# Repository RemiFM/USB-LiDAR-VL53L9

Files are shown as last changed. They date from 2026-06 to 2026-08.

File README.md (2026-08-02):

# USB-C LiDAR Node (VL53L9)



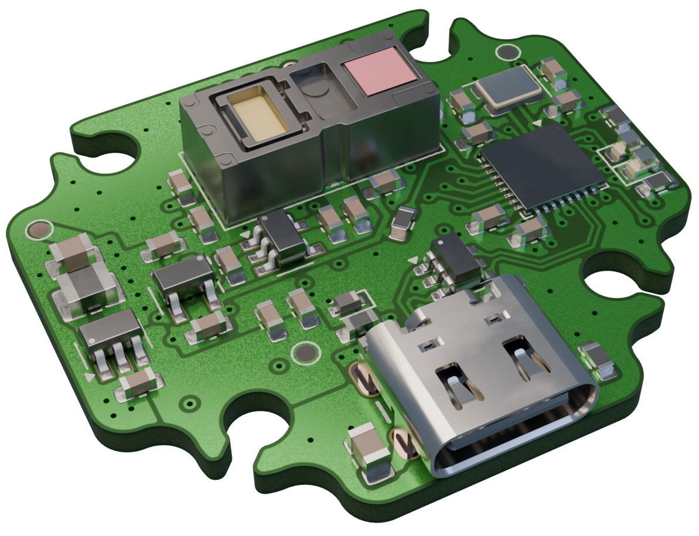
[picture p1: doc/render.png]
PCB render


A compact and low-cost USB device with integrated LiDAR sensor and IMU. This hardware node packages STMicroelectronics' VL53L9 advanced direct Time-of-Flight (dToF) matrix LiDAR with a 6-axis IMU into a plug-and-play USB-C device. Designed for mobile robotics, micro-UAVs, and academic SLAM research. The hardware is designed in KiCad 10.

## System Architecture
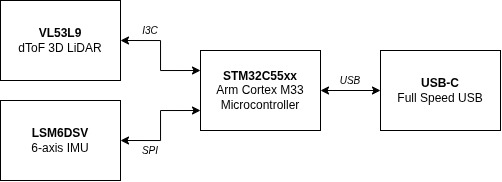
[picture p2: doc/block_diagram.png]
Block diagram showing VL53L9 LiDAR and LSM6DSV IMU connected via I3C to an STM32C55xx MCU, which interfaces to the host over USB Full-Speed


| Feature | Detail | Datasheet |
|---|---|---|
| **LiDAR** | ST VL53L9CX dToF module with up to 54×42 (2.3 k) discrete ranging zones, 5 cm–8.8 m range | [link](https://www.st.com/resource/en/datasheet/vl53l9cx.pdf)
| **IMU** | ST LSM6DSV 6-axis IMU with embedded sensor fusion engine, orientation quaternions generated on-chip | [link](https://www.st.com/resource/en/datasheet/lsm6dsv.pdf)

## Data Format
Raw binary packet framing is used instead of verbose text formats (JSON/CSV) to stay well within the 12 Mbps USB Full-Speed ceiling while imposing zero processing overhead on the MCU.

Per the VL53L9CX datasheet (DS14879, Table 2), the I3C interface is specified for a 12.5 MHz bus clock and a 12.5 Mbps output data rate. Full resolution is hard-limited to 30 Hz. Two pre-configured profiles are available:

| Profile | Output Matrix | Frame Rate |
|---|---|---|
| **Full Resolution** *(default)* | 54 × 42 zones | 30 Hz |
| **Binned Navigation** *(high-velocity)* | 24 × 20 zones | 60 Hz |

## Mechanical Specs

The PCB measures 34 × 30 mm and has 4× M3 mounting holes on a 20 mm square pitch, fitting small drone frame stacks.

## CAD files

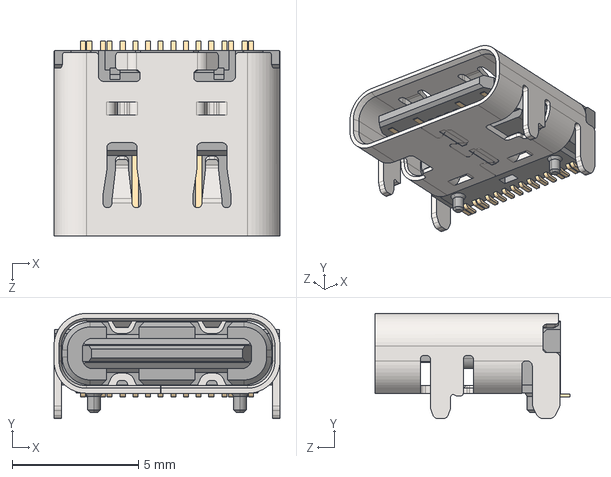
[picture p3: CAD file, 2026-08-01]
pcb/3d/USB4106-GF-A.stp
8.94 x 4.16 x 7.73 mm
HSG

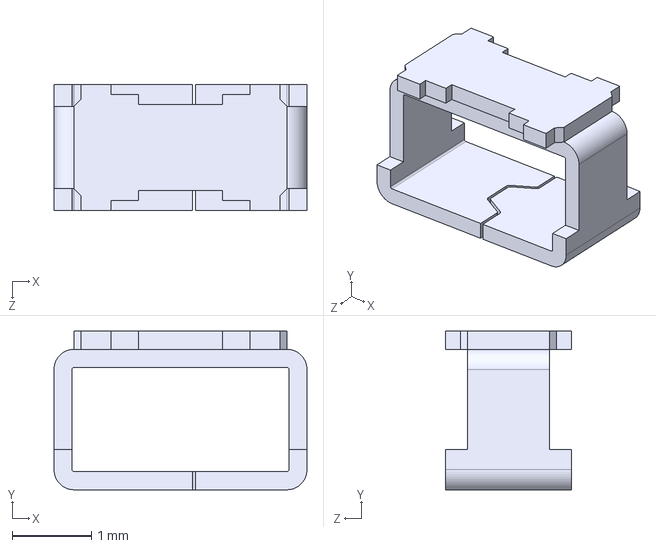
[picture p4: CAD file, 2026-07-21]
pcb/3d/RCWCTE.stp
3.20 x 2.01 x 1.60 mm

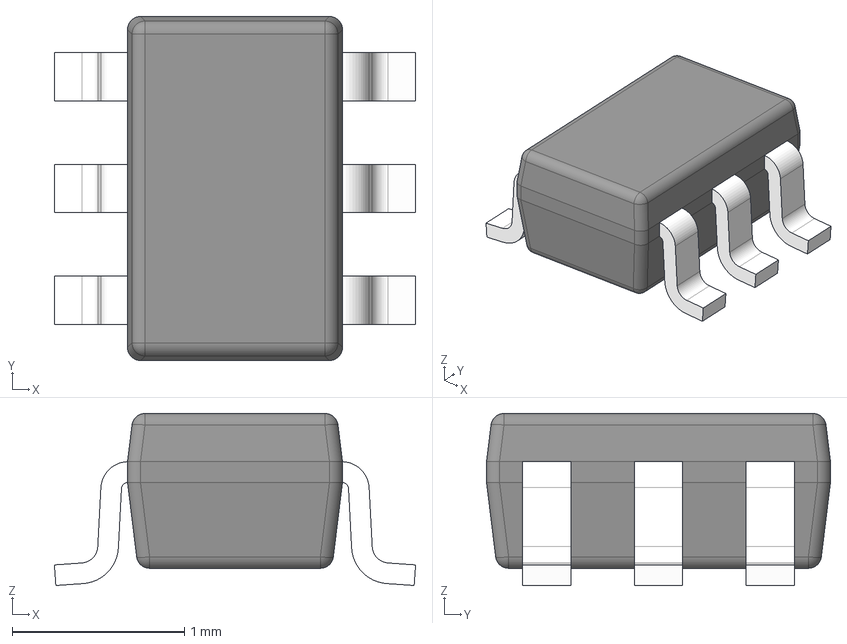
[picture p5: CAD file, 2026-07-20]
pcb/3d/DCK0006A.stp
2.10 x 2.00 x 1.00 mm
BODY-SOT
LEAD-SOT x 6
PIN1-ID

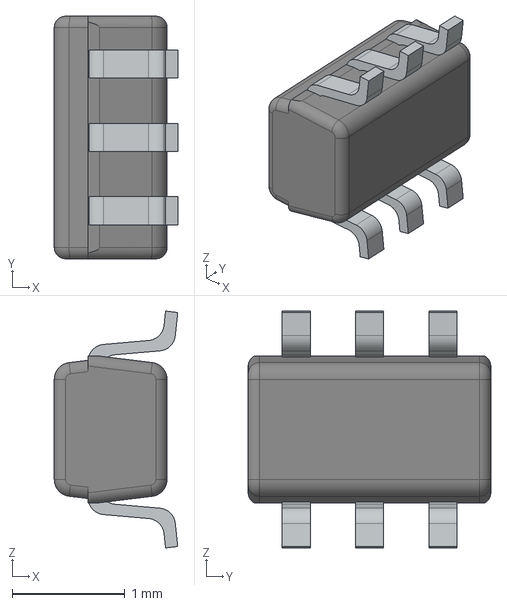
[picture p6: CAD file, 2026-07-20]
pcb/3d/Diodes-In-SOT363.stp
1.09 x 2.15 x 2.10 mm
LF01

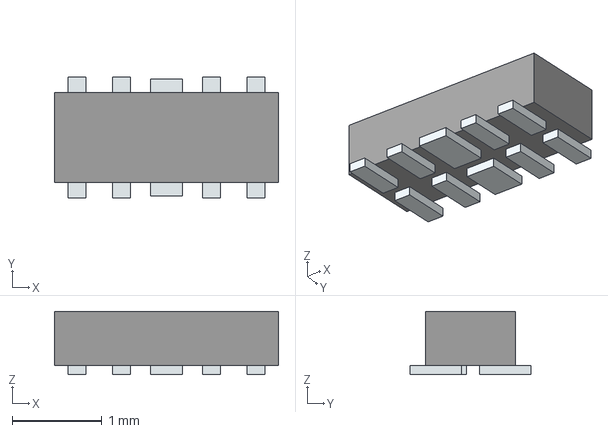
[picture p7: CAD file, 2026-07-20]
pcb/3d/D3V3X4U10LP-7.stp
2.50 x 1.35 x 0.705 mm
Pins

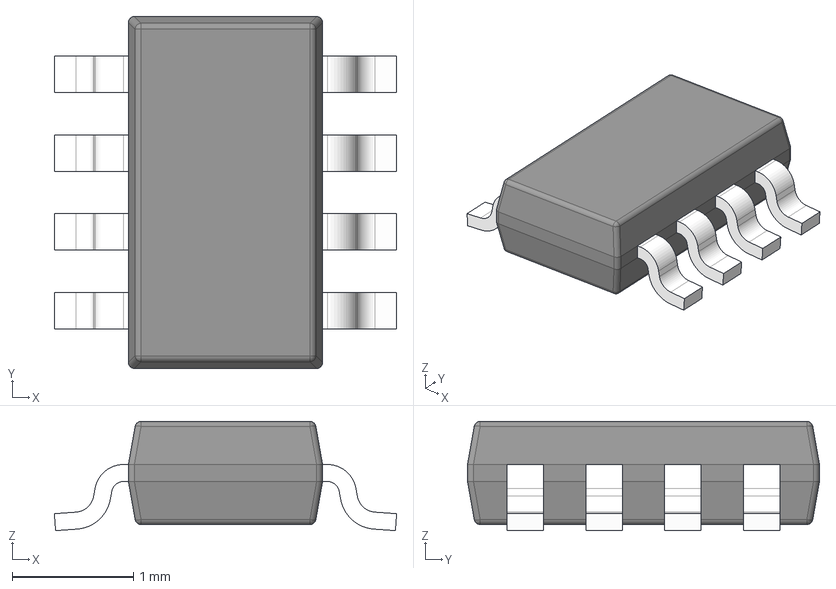
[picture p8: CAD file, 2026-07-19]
pcb/3d/DDF0008A.stp
2.82 x 2.90 x 0.9 mm
BODY-SO
LEAD-SO x 8
PIN1-ID

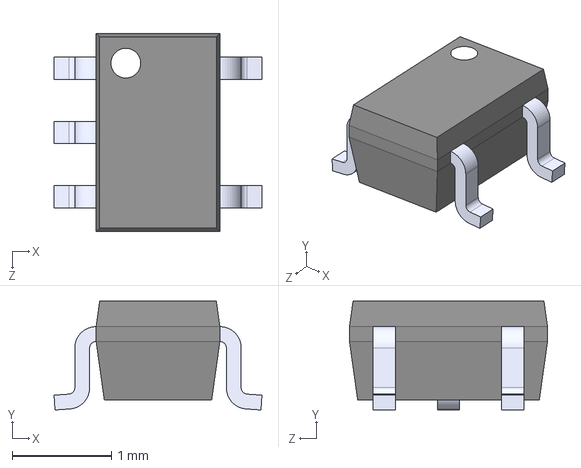
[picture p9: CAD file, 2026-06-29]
pcb/3d/SN74LVC1G17DCKR.stp
2.10 x 1.10 x 2.00 mm

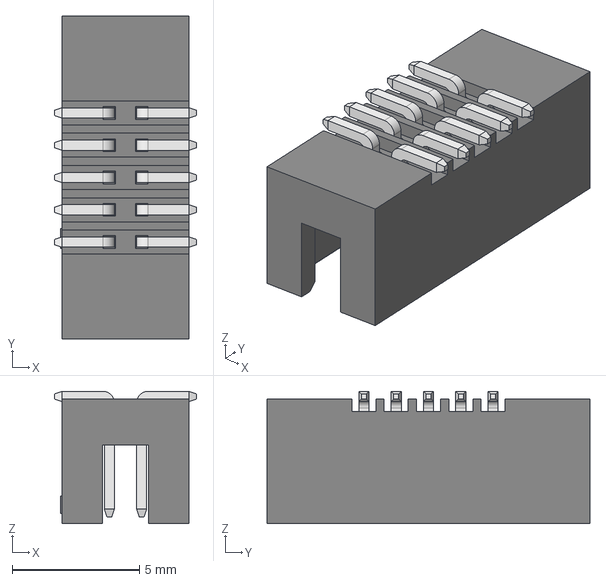
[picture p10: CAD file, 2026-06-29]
pcb/3d/3221-10-0300-00 3D.stp
5.60 x 12.7 x 5.20 mm
801-2195-10-K
2195SM-PIN x 10

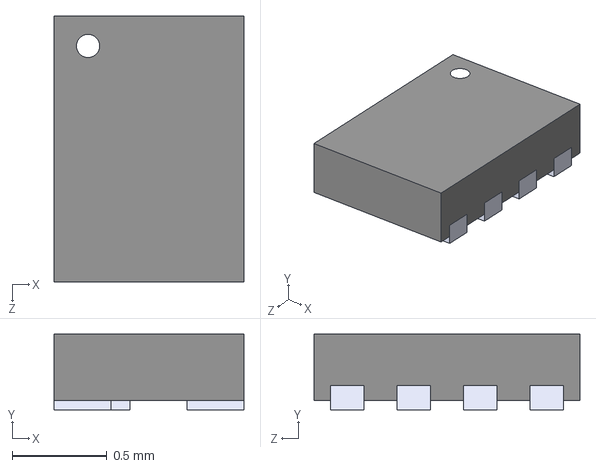
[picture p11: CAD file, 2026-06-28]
pcb/3d/LSF0102DQER.stp
1.00 x 0.4 x 1.40 mm

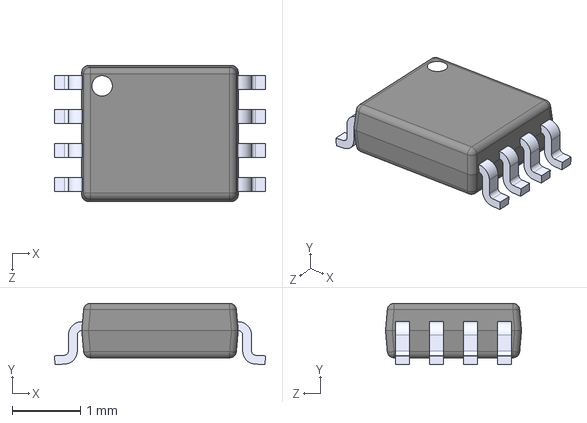
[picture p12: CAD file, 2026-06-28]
pcb/3d/LSF0102DCUR.stp
3.10 x 0.9 x 2.00 mm

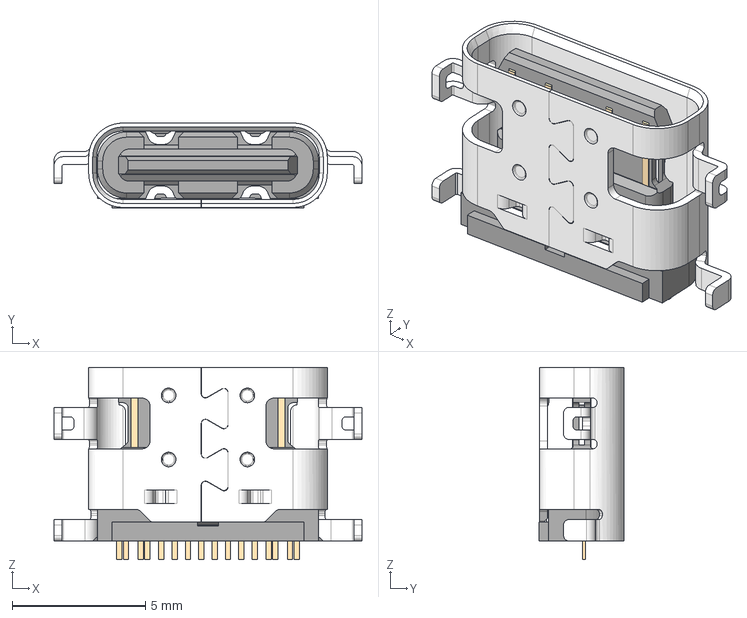
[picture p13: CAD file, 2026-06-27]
pcb/3d/USB4510-03-1-A.stp
11.5 x 3.18 x 7.20 mm

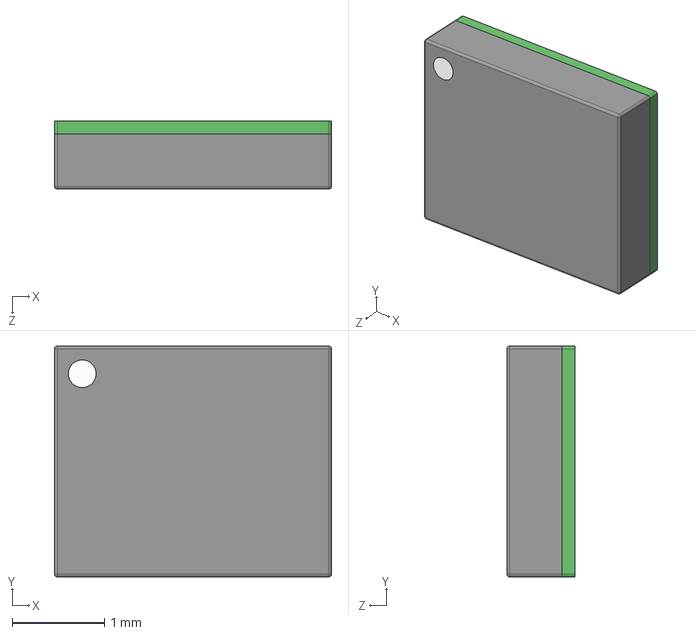
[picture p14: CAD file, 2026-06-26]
pcb/3d/LSM6DSV16BXTR.stp
3.00 x 2.50 x 0.74 mm

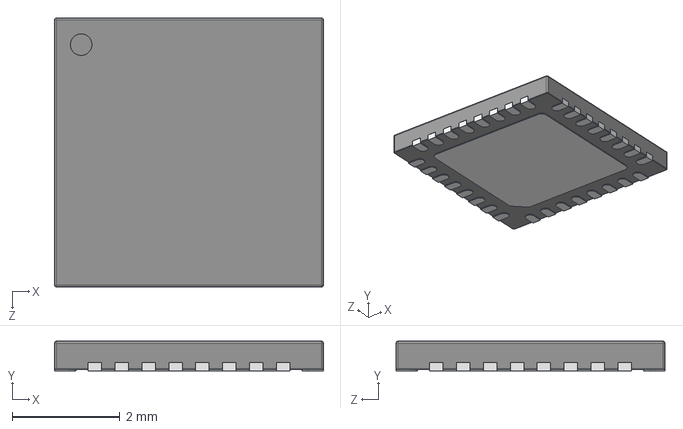
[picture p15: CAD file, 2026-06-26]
pcb/3d/STM32C551KEU6.stp
5.00 x 0.55 x 5.00 mm

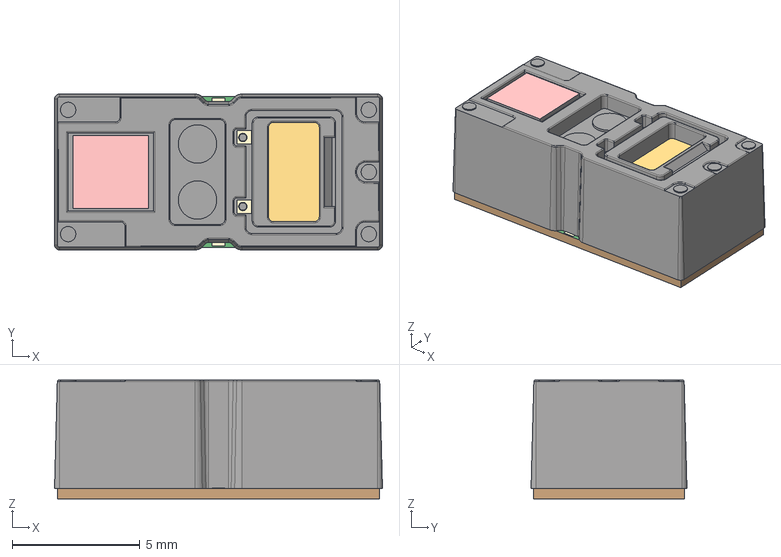
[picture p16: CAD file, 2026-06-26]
pcb/3d/VL53L9CX.stp
12.8 x 6.10 x 4.64 mm

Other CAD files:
pcb/3d/TLV73328PDBVR.stp

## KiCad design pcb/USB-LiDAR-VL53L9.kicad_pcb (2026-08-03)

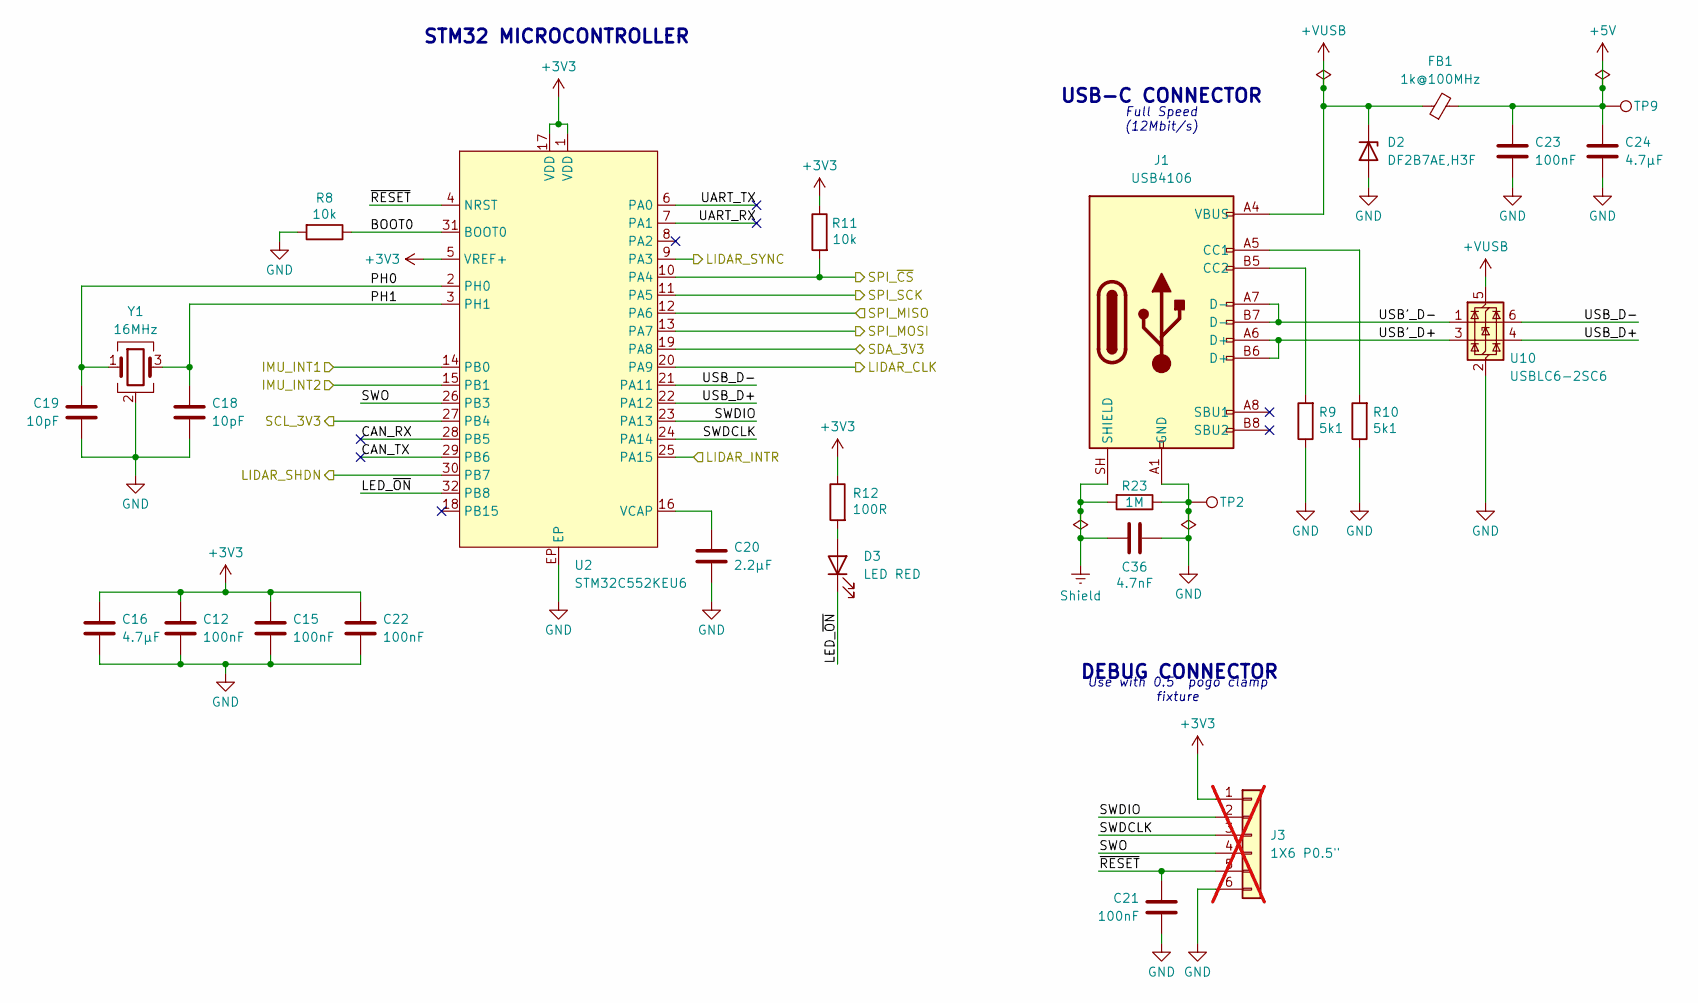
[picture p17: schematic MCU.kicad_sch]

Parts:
C12, C15, C21, C22, C23: 100nF; C_0603_1608Metric; Digi-Key 311-1088-1-ND
C16, C24: 4.7µF; C_0603_1608Metric; Digi-Key 311-1785-1-ND
C18, C19: 10pF; C_0603_1608Metric; Digi-Key 311-1058-1-ND
C20: 2.2µF; C_0603_1608Metric; Digi-Key 311-1451-1-ND
C36: 4.7nF; C_0805_2012Metric; Digi-Key 399-C0805C472KDRACTUCT-ND
D2: DF2B7AE,H3F; D_SOD-523; Digi-Key DF2B7AEH3FCT-ND
D3: LED RED; LED_0603_1608Metric; Digi-Key 160-1447-1-ND
FB1: 1k@100MHz; L_0603_1608Metric; Digi-Key 490-17349-1-ND
J1: USB4106; GCT_USB4106; Digi-Key 2073-USB4106-GF-ACT-ND
J3: 1X6 P0.5"; Connector_TH_1x06_P1.27mm; not fitted
R8, R11: 10k; R_0603_1608Metric; Digi-Key 311-10.0KHRCT-ND
R9, R10: 5k1; R_0603_1608Metric; Digi-Key 311-5.10KHRCT-ND
R12: 100R; R_0603_1608Metric; Digi-Key 311-100HRCT-ND
R23: 1M; R_0603_1608Metric; Digi-Key 13-RC0603FR-131MLCT-ND
TP2: GND; TestPoint_Pad_D1.0mm
TP9: +5V; TestPoint_Pad_D1.0mm
U2: STM32C552KEU6; ST_UFQFPN32; Digi-Key 497-STM32C552KEU6-ND
U10: USBLC6-2SC6; SOT-23-6; Digi-Key 497-5235-1-ND
Y1: 16MHz; Crystal_SMD_SeikoEpson_TSX3225-4Pin_3.2x2.5mm; Digi-Key SER4069CT-ND

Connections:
+3V3: C12.1, C15.1, C16.1, C22.1, J3.1, R11.1, R12.1, U2.1 (VDD), U2.5 (VREF+), U2.17 (VDD); also elsewhere on the board
+5V: C23.1, C24.1, FB1.2, TP9.1 (1_1); also elsewhere on the board
+VUSB: D2.1 (K), FB1.1, J1.A4 (VBUS), J1.A9 (VBUS), U10.5 (VBUS)
/IMU Sensor/IMU_INT1: U2.14 (PB0); also elsewhere on the board
/IMU Sensor/IMU_INT2: U2.15 (PB1); also elsewhere on the board
/IMU Sensor/SPI_MISO: U2.12 (PA6); also elsewhere on the board
/IMU Sensor/SPI_MOSI: U2.13 (PA7); also elsewhere on the board
/IMU Sensor/SPI_SCK: U2.11 (PA5); also elsewhere on the board
/IMU Sensor/SPI_~CS: R11.2, U2.10 (PA4); also elsewhere on the board
/LiDAR Sensor/LIDAR_CLK: U2.20 (PA9); also elsewhere on the board
/LiDAR Sensor/LIDAR_INTR: U2.25 (PA15); also elsewhere on the board
/LiDAR Sensor/LIDAR_SHDN: U2.30 (PB7); also elsewhere on the board
/LiDAR Sensor/LIDAR_SYNC: U2.9 (PA3); also elsewhere on the board
/LiDAR Sensor/SCL_3V3: U2.27 (PB4); also elsewhere on the board
/LiDAR Sensor/SDA_3V3: U2.19 (PA8); also elsewhere on the board
/Microcontroller/BOOT0: R8.1, U2.31 (BOOT0)
/Microcontroller/CAN_RX: U2.28 (PB5)
/Microcontroller/CAN_TX: U2.29 (PB6)
/Microcontroller/LED_~ON: D3.1 (K), U2.32 (PB8)
/Microcontroller/PH0: C19.1, U2.2 (PH0), Y1.1
/Microcontroller/PH1: C18.1, U2.3 (PH1), Y1.3
/Microcontroller/SWDCLK: J3.3, U2.24 (PA14)
/Microcontroller/SWDIO: J3.2, U2.23 (PA13)
/Microcontroller/SWO: J3.4, U2.26 (PB3)
/Microcontroller/UART_RX: U2.7 (PA1)
/Microcontroller/UART_TX: U2.6 (PA0)
/Microcontroller/USB'_D+: J1.A6 (D+), J1.B6 (D+), U10.3 (I/O2)
/Microcontroller/USB'_D-: J1.A7 (D-), J1.B7 (D-), U10.1 (I/O1)
/Microcontroller/USB_D+: U2.22 (PA12), U10.4 (I/O2)
/Microcontroller/USB_D-: U2.21 (PA11), U10.6 (I/O1)
/Microcontroller/~RESET: C21.1, J3.5, U2.4 (NRST)
GND: C12.2, C15.2, C16.2, C18.2, C19.2, C20.2, C21.2, C22.2, C23.2, C24.2, C36.2, D2.2 (A), J1.A1 (GND), J1.A12 (GND), J3.6, R8.2, R9.1, R10.1, R23.1, TP2.1 (1_1), U2.EP, U10.2 (GND), Y1.2 (G), Y1.4 (G); also elsewhere on the board
unnamed: D3.2 (A), R12.2
unnamed: J1.A5 (CC1), R10.2
unnamed: J1.B5 (CC2), R9.2
unnamed: C20.1, U2.16 (VCAP)
Shield: C36.1, J1.SH (SHIELD), R23.2

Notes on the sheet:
DEBUG CONNECTOR
STM32 MICROCONTROLLER
USB-C CONNECTOR
Full Speed (12Mbit/s)
Use with 0.5" pogo clamp fixture

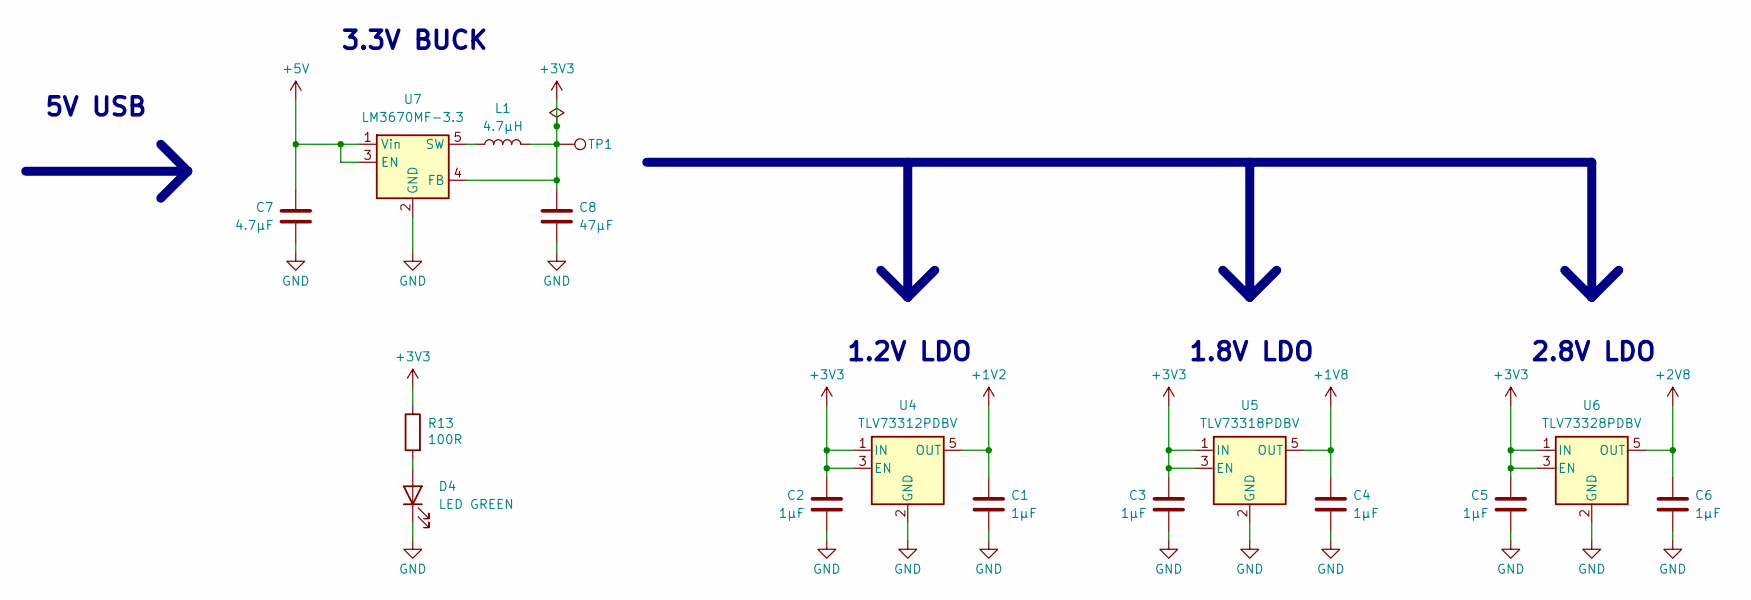
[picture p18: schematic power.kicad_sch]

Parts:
C1, C2, C3, C4, C5, C6: 1µF; C_0603_1608Metric; Digi-Key 311-1443-1-ND
C7: 4.7µF; C_0603_1608Metric; Digi-Key 311-1785-1-ND
C8: 47µF; C_0805_2012Metric; Digi-Key 311-1897-1-ND
D4: LED GREEN; LED_0603_1608Metric; Digi-Key 160-1435-1-ND
L1: 4.7µH; L_1008_2520Metric; Digi-Key 490-10651-1-ND
R13: 100R; R_0603_1608Metric; Digi-Key 311-100HRCT-ND
TP1: 3V3; TestPoint_Pad_D1.0mm
U4: TLV73312PDBV; TI_SOT23_DBV0005A; Digi-Key 296-40665-1-ND
U5: TLV73318PDBV; TI_SOT23_DBV0005A; Digi-Key 296-40669-1-ND
U6: TLV73328PDBV; TI_SOT23_DBV0005A; Digi-Key 296-42368-1-ND
U7: LM3670MF-3.3; TI_SOT23_DBV0005A; Digi-Key LM3670MF-3.3/NOPBCT-ND

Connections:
+1V2: C1.1, U4.5 (OUT); also elsewhere on the board
+1V8: C4.1, U5.5 (OUT); also elsewhere on the board
+2V8: C6.1, U6.5 (OUT); also elsewhere on the board
+3V3: C2.1, C3.1, C5.1, C8.1, L1.2, R13.1, TP1.1 (1_1), U4.1 (IN), U4.3 (EN), U5.1 (IN), U5.3 (EN), U6.1 (IN), U6.3 (EN), U7.4 (FB); also elsewhere on the board
+5V: C7.1, U7.1 (Vin), U7.3 (EN); also elsewhere on the board
GND: C1.2, C2.2, C3.2, C4.2, C5.2, C6.2, C7.2, C8.2, D4.1 (K), U4.2 (GND), U5.2 (GND), U6.2 (GND), U7.2 (GND); also elsewhere on the board
unnamed: D4.2 (A), R13.2
unnamed: L1.1, U7.5 (SW)

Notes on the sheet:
1.8V LDO
3.3V BUCK
1.2V LDO
5V USB
2.8V LDO

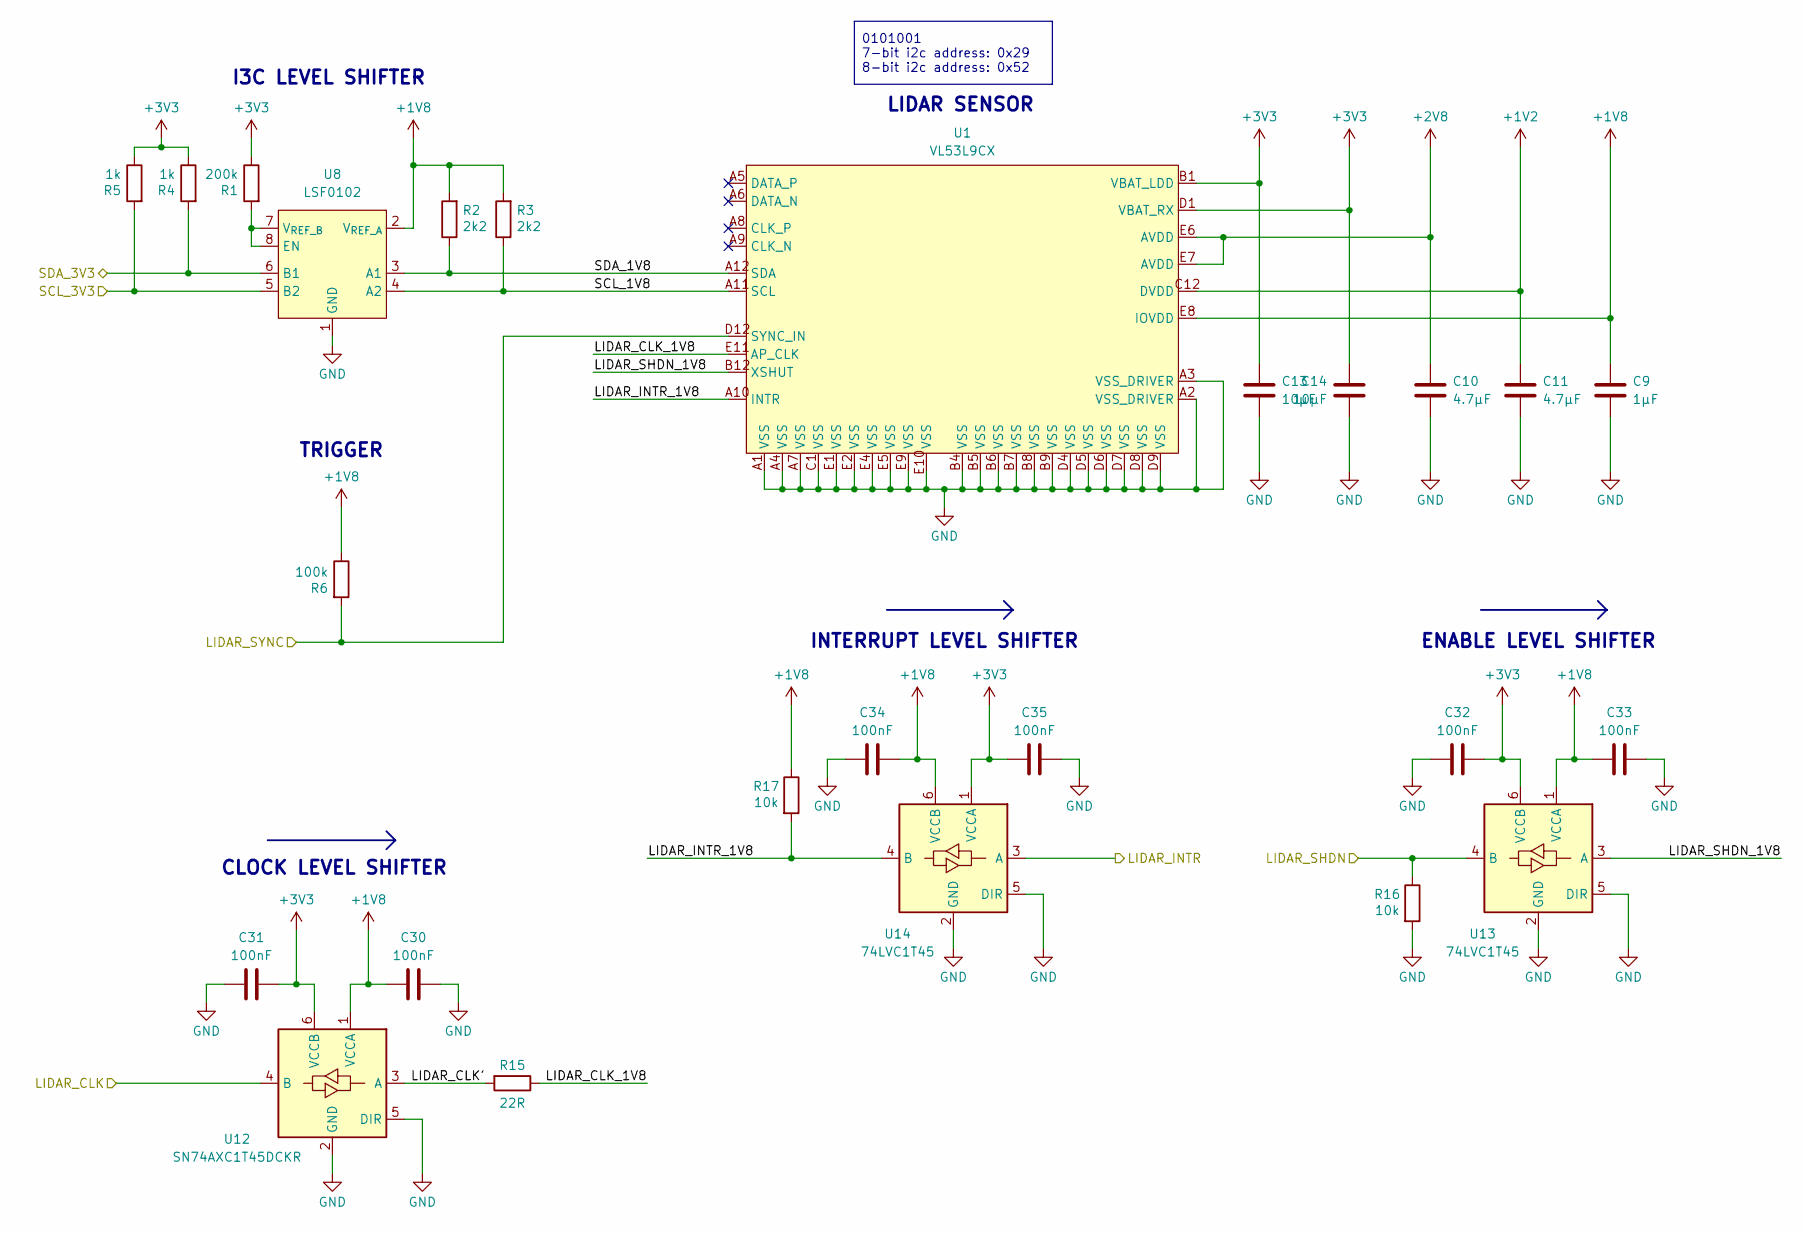
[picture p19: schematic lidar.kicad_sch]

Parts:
C9: 1µF; C_0603_1608Metric; Digi-Key 311-1443-1-ND
C10, C11: 4.7µF; C_0603_1608Metric; Digi-Key 311-1785-1-ND
C13, C14: 10µF; C_0603_1608Metric; Digi-Key 311-1817-1-ND
C30, C31, C32, C33, C34, C35: 100nF; C_0603_1608Metric; Digi-Key 311-1088-1-ND
R1: 200k; R_0603_1608Metric; Digi-Key 311-200KHRCT-ND
R2, R3: 2k2; R_0603_1608Metric; Digi-Key 311-2.20KHRCT-ND
R4, R5: 1k; R_0603_1608Metric; Digi-Key 311-1.00KHRCT-ND
R6: 100k; R_0603_1608Metric; Digi-Key 311-100KHRCT-ND
R15: 22R; R_0603_1608Metric; Digi-Key 311-22.0HRCT-ND
R16, R17: 10k; R_0603_1608Metric; Digi-Key 311-10.0KHRCT-ND
U1: VL53L9CX; ST_VL53L9CX
U8: LSF0102; TI_VSSOP_DCU0008A; Digi-Key 296-39070-1-ND
U12: SN74AXC1T45DCKR; TI_SOT363-DCK0006A; Digi-Key 296-48341-1-ND
U13, U14: 74LVC1T45; Diodes_Inc_SOT363; Digi-Key 31-74LVC1T45DW-7CT-ND

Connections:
+1V2: C11.1, U1.C12 (DVDD); also elsewhere on the board
+1V8: C9.1, C30.2, C33.2, C34.2, R2.2, R3.2, R6.1, R17.1, U1.E8 (IOVDD), U8.2 (V_{REF_A}), U12.1 (VCCA), U13.1 (VCCA), U14.6 (VCCB); also elsewhere on the board
+2V8: C10.1, U1.E6 (AVDD), U1.E7 (AVDD); also elsewhere on the board
+3V3: C13.1, C14.1, C31.2, C32.2, C35.2, R1.1, R4.1, R5.1, U1.B1 (VBAT_LDD), U1.D1 (VBAT_RX), U12.6 (VCCB), U13.6 (VCCB), U14.1 (VCCA); also elsewhere on the board
/LiDAR Sensor/LIDAR_CLK: U12.4 (B); also elsewhere on the board
/LiDAR Sensor/LIDAR_CLK': R15.2, U12.3 (A)
/LiDAR Sensor/LIDAR_CLK_1V8: R15.1, U1.E11 (AP_CLK)
/LiDAR Sensor/LIDAR_INTR: U14.3 (A); also elsewhere on the board
/LiDAR Sensor/LIDAR_INTR_1V8: R17.2, U1.A10 (INTR), U14.4 (B)
/LiDAR Sensor/LIDAR_SHDN: R16.1, U13.4 (B); also elsewhere on the board
/LiDAR Sensor/LIDAR_SHDN_1V8: U1.B12 (XSHUT), U13.3 (A)
/LiDAR Sensor/LIDAR_SYNC: R6.2, U1.D12 (SYNC_IN); also elsewhere on the board
/LiDAR Sensor/SCL_1V8: R3.1, U1.A11 (SCL), U8.4 (A2)
/LiDAR Sensor/SCL_3V3: R5.2, U8.5 (B2); also elsewhere on the board
/LiDAR Sensor/SDA_1V8: R2.1, U1.A12 (SDA), U8.3 (A1)
/LiDAR Sensor/SDA_3V3: R4.2, U8.6 (B1); also elsewhere on the board
GND: C9.2, C10.2, C11.2, C13.2, C14.2, C30.1, C31.1, C32.1, C33.1, C34.1, C35.1, R16.2, U1.A1 (VSS), U1.A2 (VSS_DRIVER), U1.A3 (VSS_DRIVER), U1.A4 (VSS), U1.A7 (VSS), U1.B4 (VSS), U1.B5 (VSS), U1.B6 (VSS), U1.B7 (VSS), U1.B8 (VSS), U1.B9 (VSS), U1.C1 (VSS), U1.D4 (VSS), U1.D5 (VSS), U1.D6 (VSS), U1.D7 (VSS), U1.D8 (VSS), U1.D9 (VSS), U1.E1 (VSS), U1.E2 (VSS), U1.E4 (VSS), U1.E5 (VSS), U1.E9 (VSS), U1.E10 (VSS), U8.1 (GND), U12.2 (GND), U12.5 (DIR), U13.2 (GND), U13.5 (DIR), U14.2 (GND), U14.5 (DIR); also elsewhere on the board
unnamed: R1.2, U8.7 (V_{REF_B}), U8.8 (EN)

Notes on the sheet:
ENABLE LEVEL SHIFTER
INTERRUPT LEVEL SHIFTER
TRIGGER
LIDAR SENSOR
I3C LEVEL SHIFTER
CLOCK LEVEL SHIFTER
0101001 7-bit i2c address: 0x29 8-bit i2c address: 0x52

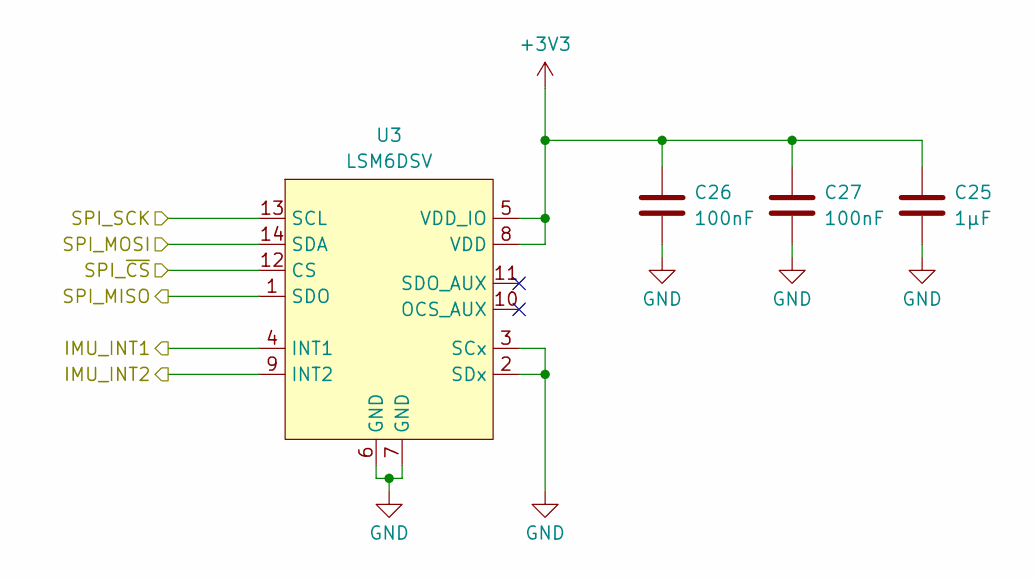
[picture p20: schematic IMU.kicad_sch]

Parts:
C25: 1µF; C_0603_1608Metric; Digi-Key 311-1443-1-ND
C26, C27: 100nF; C_0603_1608Metric; Digi-Key 311-1088-1-ND
U3: LSM6DSV; ST_LSM6DSV; Digi-Key 497-LSM6DSV16BXTRCT-ND

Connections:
+3V3: C25.1, C26.1, C27.1, U3.5 (VDD_IO), U3.8 (VDD); also elsewhere on the board
/IMU Sensor/IMU_INT1: U3.4 (INT1); also elsewhere on the board
/IMU Sensor/IMU_INT2: U3.9 (INT2); also elsewhere on the board
/IMU Sensor/SPI_MISO: U3.1 (SDO); also elsewhere on the board
/IMU Sensor/SPI_MOSI: U3.14 (SDA); also elsewhere on the board
/IMU Sensor/SPI_SCK: U3.13 (SCL); also elsewhere on the board
/IMU Sensor/SPI_~CS: U3.12 (CS); also elsewhere on the board
GND: C25.2, C26.2, C27.2, U3.2 (SDx), U3.3 (SCx), U3.6 (GND), U3.7 (GND); also elsewhere on the board

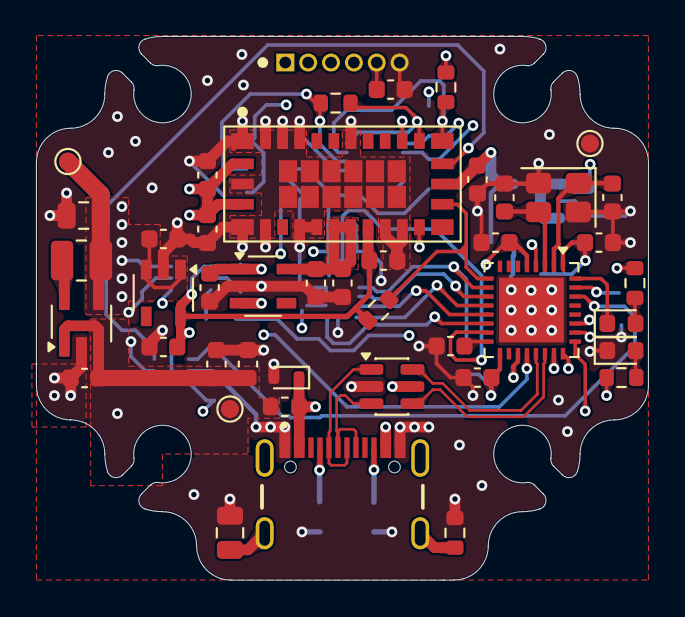
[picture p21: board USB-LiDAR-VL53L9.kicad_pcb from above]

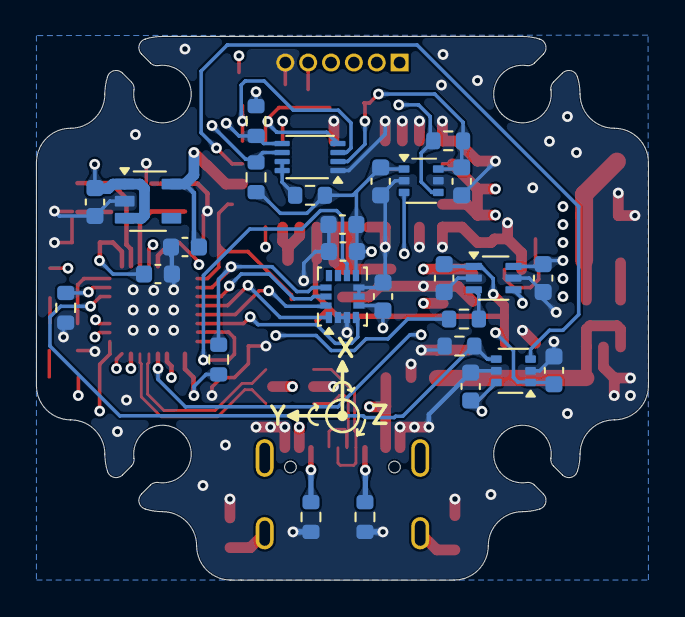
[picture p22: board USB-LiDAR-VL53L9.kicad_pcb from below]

Board: 6 copper layers, 34.0 x 30.2 mm, 72 parts (28 on the bottom side), 45 nets.

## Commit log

2026-06-26 project setup
    [USB-LiDAR-VL53L9.kicad_pcb, USB-LiDAR-VL53L9.kicad_sch]
2026-06-26 VL53L9 footprint & symbol
    [USB-LiDAR-VL53L9.kicad_pcb, USB-LiDAR-VL53L9.kicad_sch, VL53L9CX.stp]
2026-06-26 STM32C551KEU6 symbol & footprint
    [STM32C551KEU6.stp, USB-LiDAR-VL53L9.kicad_pcb, USB-LiDAR-VL53L9.kicad_sch]
2026-06-26 IMU symbol & footprint
    [LSM6DSV16BXTR.stp, USB-LiDAR-VL53L9.kicad_pcb, USB-LiDAR-VL53L9.kicad_sch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]
2026-06-27 USB-C footprint & symbol
    [USB-LiDAR-VL53L9.kicad_pcb, USB-LiDAR-VL53L9.kicad_sch, USB4500-03-1-A.stp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]
2026-06-27 Power footprints, symbols & schematic
    [TLV73328PDBVR.stp, USB-LiDAR-VL53L9.kicad_pcb, USB-LiDAR-VL53L9.kicad_sch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]
2026-06-28 I3C level shifting
    [IMU.kicad_sch, LSF0102DCUR.stp, LSF0102DQER.stp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]
2026-06-29 MCU schematic
    [3221-10-0300-00 3D.stp, IMU.kicad_sch, MCU.kicad_sch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]
2026-07-08 IMU connections
    [IMU.kicad_sch, MCU.kicad_sch, USB-LiDAR-VL53L9.kicad_pcb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]
2026-07-19 CAN schematic
    [CAN.kicad_sch, DDF0008A.stp, MCU.kicad_sch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]
2026-07-20 Schematic sprint
    [CAN.kicad_sch, D3V3X4U10LP-7.stp, DCK0006A.stp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]
2026-07-21 Floorplanning, no way 30x30mm board will work :(
    [MCU.kicad_sch, RCWCTE.stp, USB-LiDAR-VL53L9.kicad_pcb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]
2026-07-22 New PCB Board Shape
    [USB-LiDAR-VL53L9.kicad_pcb]
2026-07-22 Fix typo in device description
    Removed the word 'An' at the beginning of the device description for clarity.
2026-07-29 PCB floorplanning
    [USB-LiDAR-VL53L9.kicad_pcb]
2026-08-01 removed JST connector with CAN & UART
    [MCU.kicad_sch, USB-LiDAR-VL53L9.kicad_pcb, USB-LiDAR-VL53L9.kicad_sch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]
2026-08-02 Production files
    [USB-LiDAR-VL53L9.kicad_pcb]
2026-08-02 Update PCB dimensions in README
2026-08-02 Corrected production files
    [USB-LiDAR-VL53L9.kicad_pcb, USB-LiDAR-VL53L9.kicad_sch]
2026-08-02 Added PCB render
2026-08-03 Added teardrops
    [USB-LiDAR-VL53L9.kicad_pcb]
2026-08-09 Generated BOM
2026-08-09 Adjust PCB render image size in README
    Updated image size in README from 90% to 60%.
2026-09-12 Started PCB validation

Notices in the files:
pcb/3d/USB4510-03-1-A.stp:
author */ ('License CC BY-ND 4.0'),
